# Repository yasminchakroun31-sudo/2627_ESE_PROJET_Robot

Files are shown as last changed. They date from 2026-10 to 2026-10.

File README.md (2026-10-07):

# 2627_ESE_PROJET_PAC-Man🤖🗑️
PAC-Man 

### Équipe
- **Yesmine Chakroun** (yasminechakroun31-sudo)
- **Wejdene Hazami**
- **Roua Jaouadi**

### Objectif
Concevoir un robot mobile qui repère, attrape, différencie et dépose des canettes en fonction de leur couleur.

### Timeline
- **Challenge:** 15 janvier 2027
- **Fin semestre:** 16 janvier 2027

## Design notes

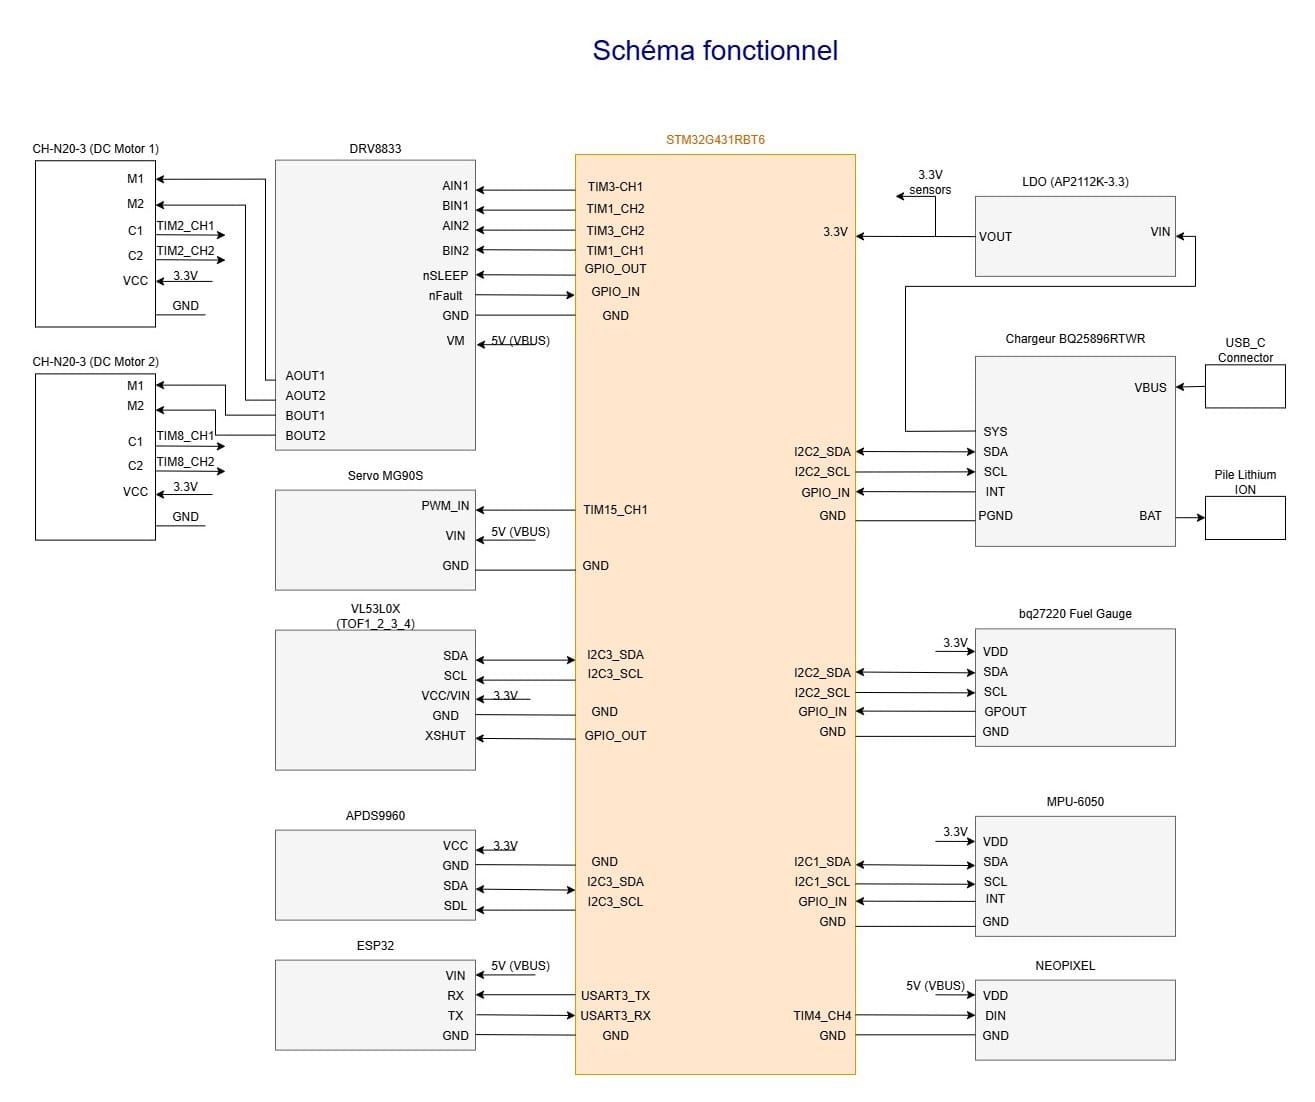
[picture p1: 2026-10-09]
docs/schema_fonctionnel.png/Schéma_Fonctionnel.jpeg

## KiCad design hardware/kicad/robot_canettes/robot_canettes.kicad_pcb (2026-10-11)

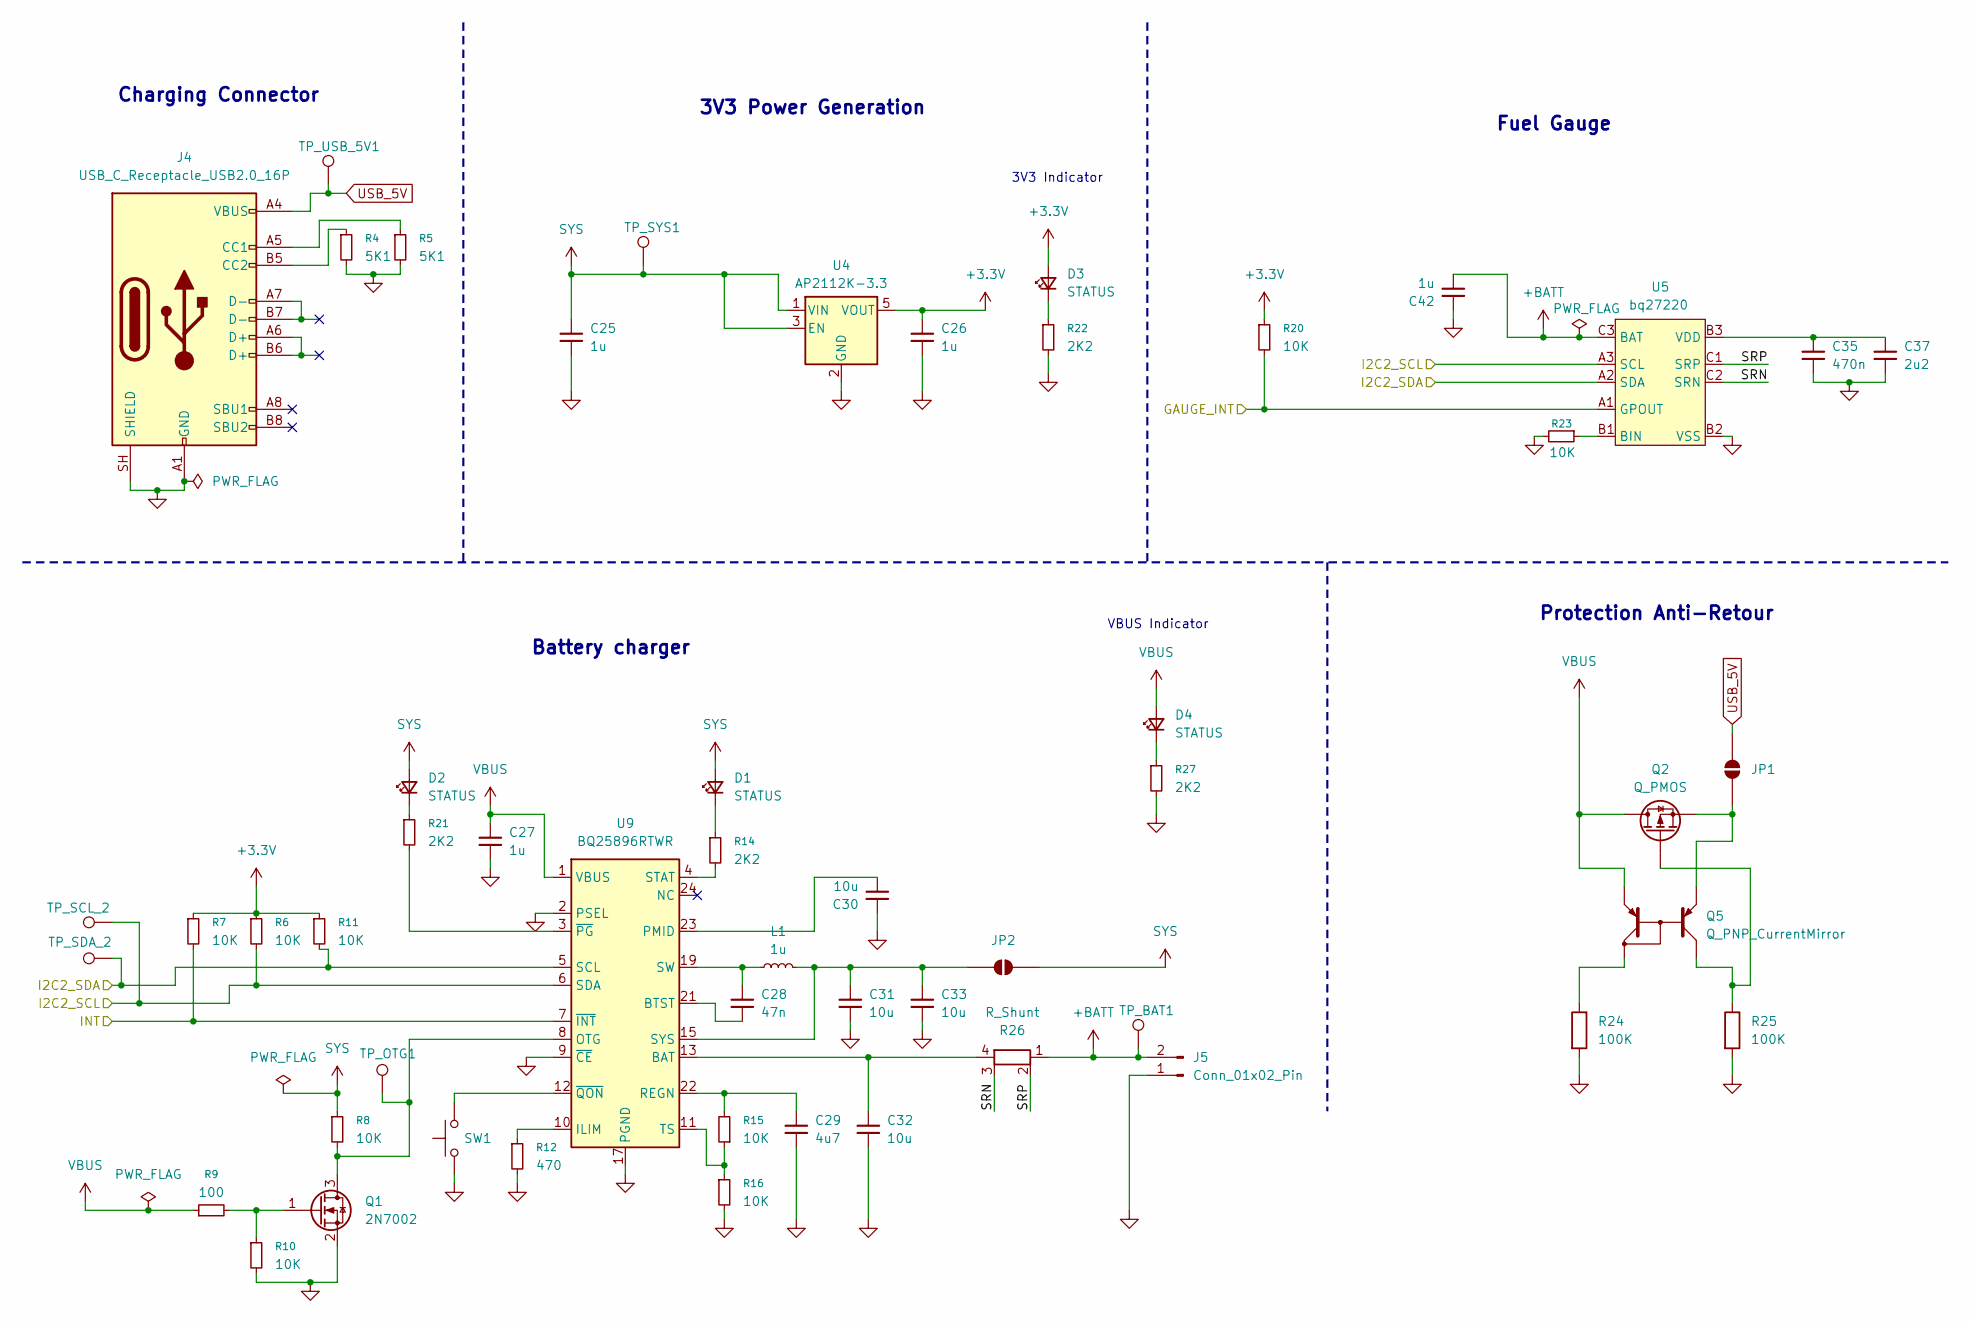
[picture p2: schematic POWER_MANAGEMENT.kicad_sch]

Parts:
C25, C26, C27, C42: 1u; C_0402_1005Metric; JLCPCB Part # C52923
C28: 47n; C_0402_1005Metric; JLCPCB Part # C5254486
C29: 4u7; C_0402_1005Metric; JLCPCB Part # C368809
C30, C31, C32, C33: 10u; C_0603_1608Metric; JLCPCB Part # C19702
C35: 470n; C_0402_1005Metric; JLCPCB Part # C2443202
C37: 2u2; C_0402_1005Metric; JLCPCB Part # C107370
D1: STATUS; LED_0603_1608Metric; JLCPCB Part # C2287
D2, D3, D4: STATUS; LED_0603_1608Metric; JLCPCB Part # C72043
J4: USB_C_Receptacle_USB2.0_16P; USB_C_Receptacle_GCT_USB4105-xx-A_16P_TopMnt_Horizontal; JLCPCB Part # C2765186
J5: Conn_01x02_Pin; JST_PH_B2B-PH-K_1x02_P2.00mm_Vertical
JP1, JP2: SolderJumper-2_P1.3mm_Open_Pad1.0x1.5mm
L1: 1u; L_APV_ANR4010; JLCPCB Part # C354578
Q1: 2N7002; SOT-23; JLCPCB Part # C8485
Q2: Q_PMOS; SOT-23; JLCPCB Part # C177033
Q5: Q_PNP_CurrentMirror; SOT-363_SC-70-6; JLCPCB Part # C42387345
R4, R5: 5K1; R_0402_1005Metric; JLCPCB Part # C25905
R6, R7, R8, R10, R11, R15, R16, R20, R23: 10K; R_0402_1005Metric; JLCPCB Part # C844714
R9: 100; R_0402_1005Metric; JLCPCB Part # C25076
R12: 470; R_0402_1005Metric; JLCPCB Part # C25117
R14, R21, R22, R27: 2K2; R_0402_1005Metric; JLCPCB Part # C25879
R24, R25: 100K; R_0603_1608Metric; JLCPCB Part # C25803
R26: R_Shunt; R_Shunt_Ohmite_LVK12; JLCPCB Part # C500740
SW1: SW_SPST_Omron_B3FS-101xP; JLCPCB Part # C271753
TP_BAT1: TestPoint_Pad_D1.5mm
TP_OTG1: TestPoint_Pad_D1.5mm
TP_SCL_2: TestPoint_Pad_D1.5mm
TP_SDA_2: TestPoint_Pad_D1.5mm
TP_SYS1: TestPoint_Pad_D1.5mm
TP_USB_5V1: TestPoint_Pad_D1.5mm
U4: AP2112K-3.3; SOT-23-5; JLCPCB Part # C51118
U5: bq27220; BGA-9_3x3_1.62x1.58mm_Pitch0.5mm; JLCPCB Part # C528617
U9: BQ25896RTWR; Texas_RTW_WQFN-24-1EP_4x4mm_P0.5mm_EP2.7x2.7mm_ThermalVias; JLCPCB Part # C181475

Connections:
+3.3V: C26.1, D3.2 (A), R6.1, R7.1, R11.1, R20.1, U4.5 (VOUT); also elsewhere on the board
+BATT: C42.2, J5.2, R26.1, TP_BAT1.1 (1_1), U5.C3 (BAT)
/MCU/GAUGE_INT: R20.2, U5.A1 (GPOUT); also elsewhere on the board
/MCU/I2C2_SCL: R6.2, TP_SCL_2.1 (1_1), U5.A3 (SCL), U9.6 (SDA); also elsewhere on the board
/MCU/I2C2_SDA: R11.2, TP_SDA_2.1 (1_1), U5.A2 (SDA), U9.5 (SCL); also elsewhere on the board
/MCU/INT: R7.2, U9.7 (~INT); also elsewhere on the board
/POWER_MANAGEMENT/SRN: R26.3, U5.C2 (SRN)
/POWER_MANAGEMENT/SRP: R26.2, U5.C1 (SRP)
unnamed: C28.1, L1.1, U9.19 (SW), U9.20 (SW)
unnamed: C32.1, R26.4, U9.13 (BAT), U9.14 (BAT)
unnamed: D1.1 (K), R14.1
unnamed: D2.1 (K), R21.1
unnamed: D3.1 (K), R22.1
unnamed: D4.1 (K), R27.1
unnamed: J4.A5 (CC1), R5.1
unnamed: J4.B5 (CC2), R4.1
unnamed: JP1.1 (A), Q2.2 (S), Q5.1 (E1)
unnamed: C31.1, C33.1, JP2.2 (B), L1.2, U9.15 (SYS), U9.16 (SYS)
unnamed: Q1.3 (D), R8.2, TP_OTG1.1 (1_1), U9.8 (OTG)
unnamed: Q1.1 (G), R9.2, R10.1
unnamed: Q2.1 (G), Q5.6 (C1), R25.1
unnamed: Q5.3 (C2), R24.1
unnamed: R23.1, U5.B1 (BIN)
unnamed: C35.1, C37.1, U5.B3 (VDD)
unnamed: C28.2, U9.21 (BTST)
unnamed: R12.1, U9.10 (ILIM)
unnamed: C30.2, U9.23 (PMID)
unnamed: C29.1, R15.2, U9.22 (REGN)
unnamed: R14.2, U9.4 (STAT)
unnamed: R15.1, R16.1, U9.11 (TS)
unnamed: R21.2, U9.3 (~PG)
unnamed: SW1.2, U9.12 (~QON)
SYS: C25.1, D1.2 (A), D2.2 (A), JP2.1 (A), R8.1, TP_SYS1.1 (1_1), U4.1 (VIN), U4.3 (EN)
USB_5V: J4.A4 (VBUS), J4.A9 (VBUS), J4.B4 (VBUS), J4.B9 (VBUS), JP1.2 (B), TP_USB_5V1.1 (1_1)
VBUS: C27.1, D4.2 (A), Q2.3 (D), Q5.4 (E2), R9.1, U9.1 (VBUS); also elsewhere on the board

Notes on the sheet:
Battery charger
Charging Connector
3V3 Indicator
Fuel Gauge
3V3 Power Generation
Protection Anti-Retour
VBUS Indicator

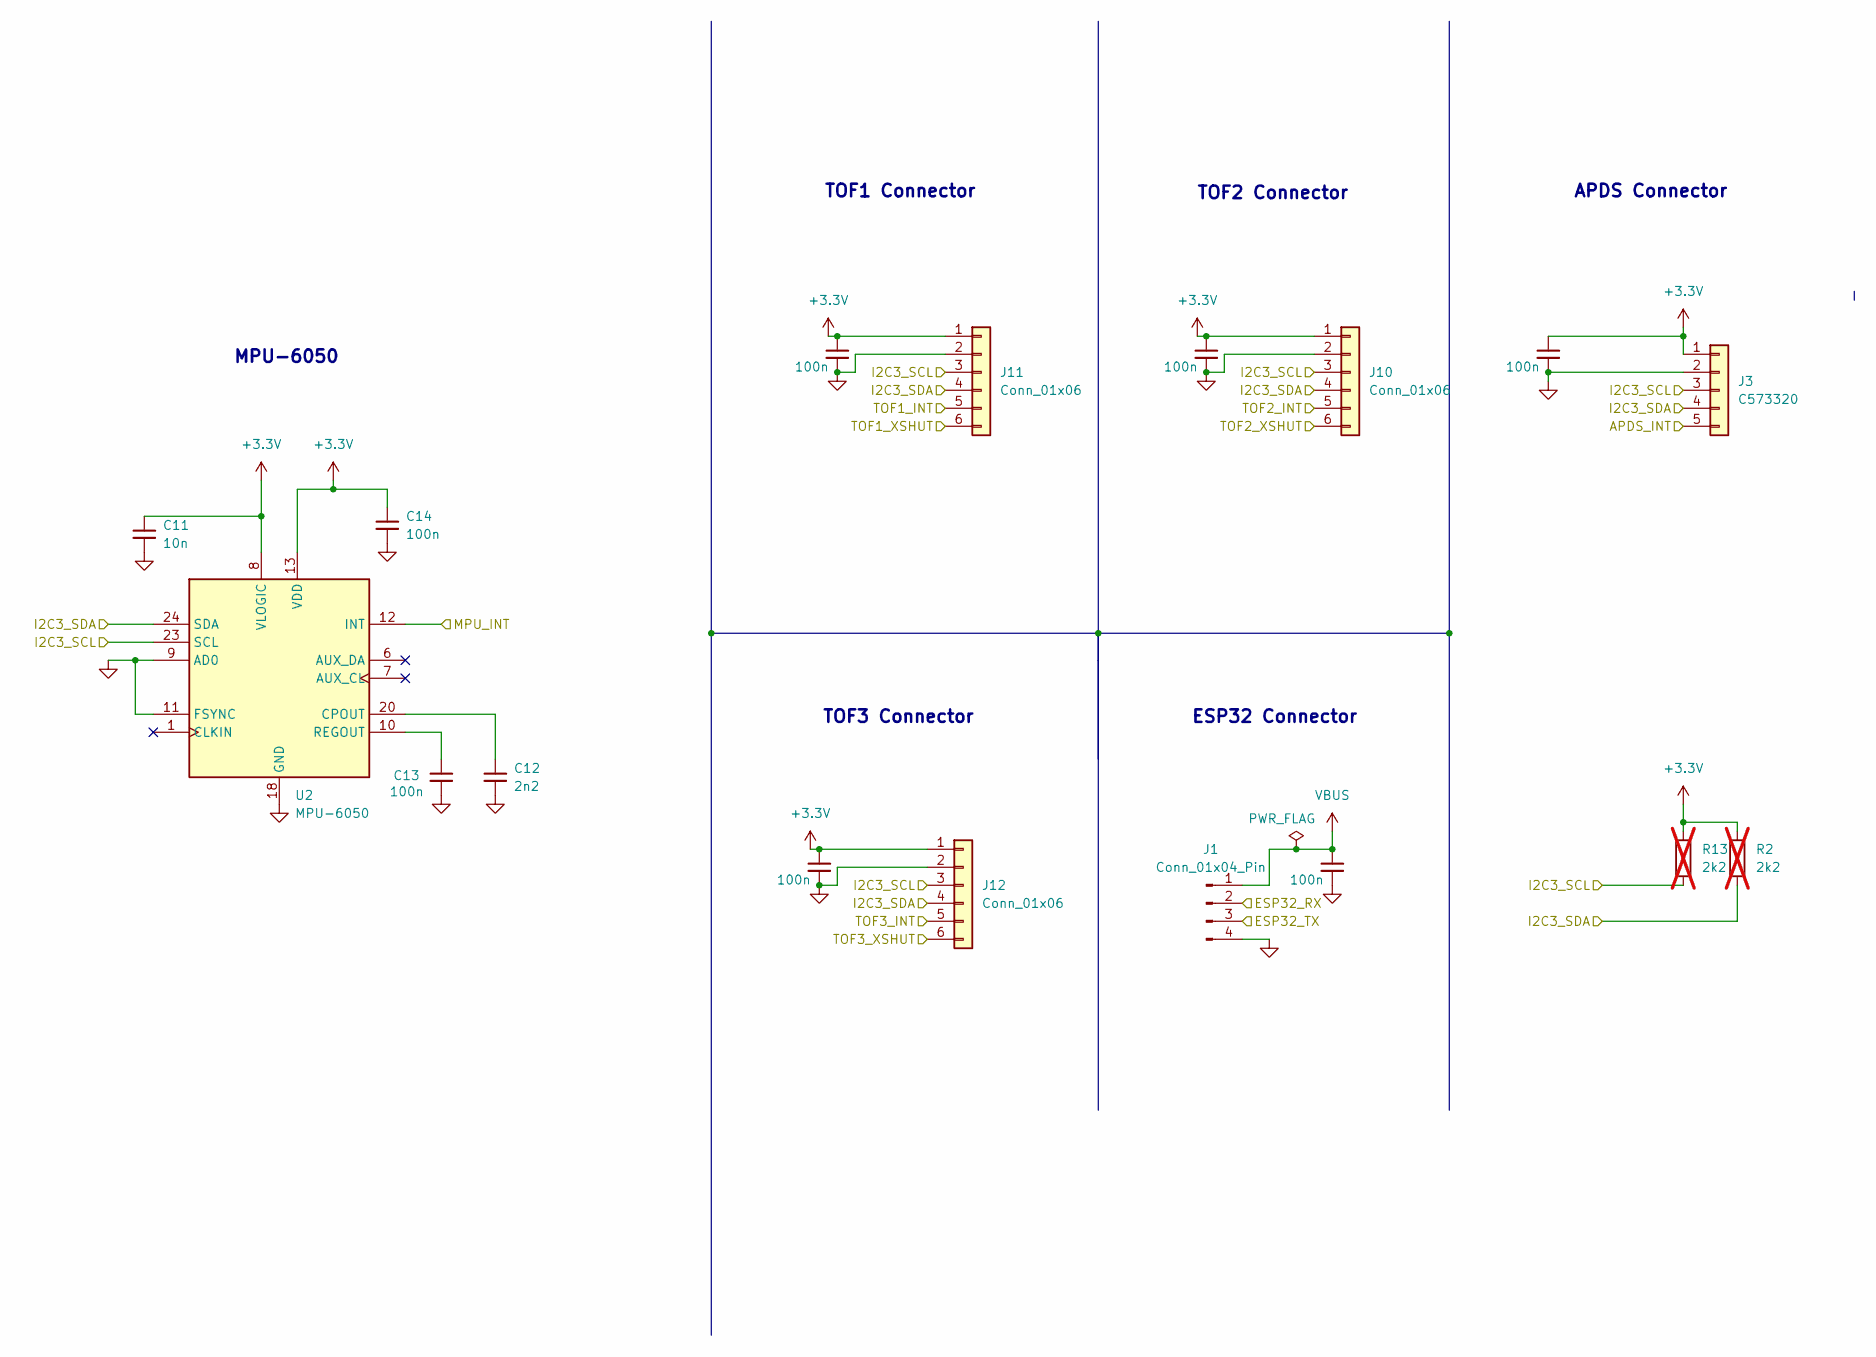
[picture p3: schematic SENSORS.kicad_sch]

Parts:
C11: 10n; C_0402_1005Metric; JLCPCB PART # C15195
C12: 2n2; C_0402_1005Metric; JLCPCB PART # C1531
C13, C14, C38, C39, C40, C41, C43: 100n; C_0402_1005Metric; JLCPCB PART # C1525
J1: Conn_01x04_Pin; JST_PH_B4B-PH-K_1x04_P2.00mm_Vertical
J3: C573320; JST_PH_B5B-PH-K_1x05_P2.00mm_Vertical; JLCPCB PART# C573320
J10, J11, J12: Conn_01x06; JST_PH_B6B-PH-K_1x06_P2.00mm_Vertical
R2, R13: 2k2; R_0402_1005Metric; JLCPCB PART # C174143; not fitted
U2: MPU-6050; InvenSense_QFN-24_4x4mm_P0.5mm; JLCPCB PART # C24112

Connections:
+3.3V: C11.1, C14.1, C38.1, C39.1, C40.1, C41.1, J3.1, J10.1, J11.1, J12.1, R2.1, R13.1, U2.8 (VLOGIC), U2.13 (VDD); also elsewhere on the board
/MCU/APDS_INT: J3.5; also elsewhere on the board
/MCU/ESP32_RX: J1.3; also elsewhere on the board
/MCU/ESP32_TX: J1.2; also elsewhere on the board
/MCU/I2C3_SCL: J3.3, J10.3, J11.3, J12.3, R13.2, U2.23 (SCL); also elsewhere on the board
/MCU/I2C3_SDA: J3.4, J10.4, J11.4, J12.4, R2.2, U2.24 (SDA); also elsewhere on the board
/MCU/MPU_INT: U2.12 (INT); also elsewhere on the board
/MCU/TOF1_INT: J12.5; also elsewhere on the board
/MCU/TOF1_XSHUT: J12.6; also elsewhere on the board
/MCU/TOF2_INT: J10.5; also elsewhere on the board
/MCU/TOF2_XSHUT: J10.6; also elsewhere on the board
/MCU/TOF3_INT: J11.5; also elsewhere on the board
/MCU/TOF3_XSHUT: J11.6; also elsewhere on the board
unnamed: C12.1, U2.20 (CPOUT)
unnamed: C13.1, U2.10 (REGOUT)
VBUS: C43.1, J1.1; also elsewhere on the board

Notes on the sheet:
TOF1 Connector
APDS Connector
ESP32 Connector
TOF2 Connector
MPU-6050
TOF3 Connector

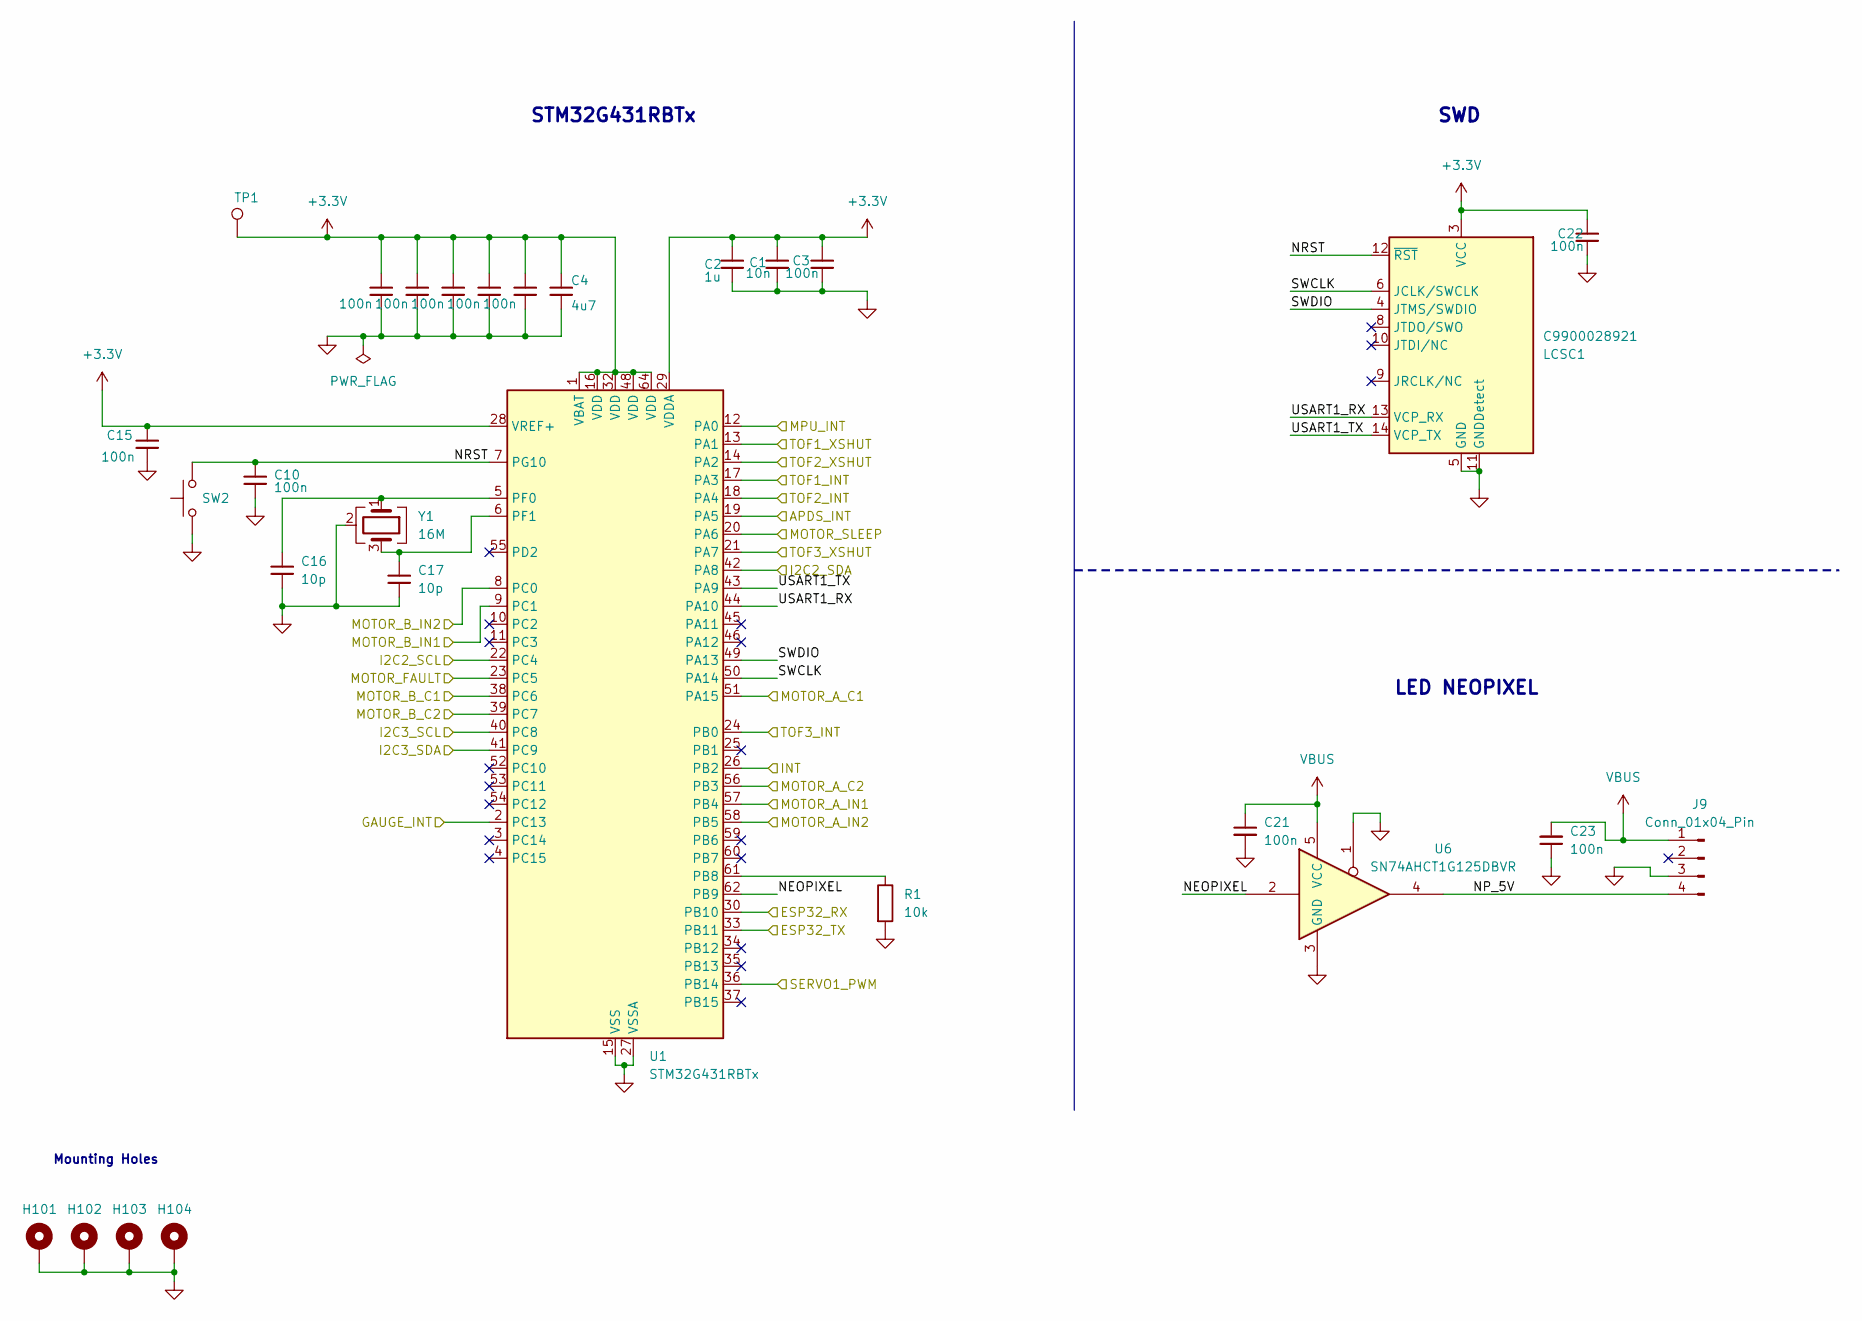
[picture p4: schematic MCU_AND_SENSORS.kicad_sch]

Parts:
C1: 10n; C_0402_1005Metric; JLCPCB PART# C15195
C2: 1u; C_0603_1608Metric; JLCPCB PART # C141772
C3, C6, C7, C8, C9, C10, C15, C22: 100n; C_0402_1005Metric; JLCPCB PART # C1525
C4: 4u7; C_0603_1608Metric
C5: 100n; C_0402_1005Metric
C16, C17: 10p; C_0603_1608Metric; JLCPCB PART # C123155
C21, C23: 100n; C_0402_1005Metric; JLCPCB Part # C1525
H101, H102, H103, H104: MountingHole_Pad; MountingHole_3.2mm_M3_Pad_Via
J9: Conn_01x04_Pin; JST_PH_B4B-PH-K_1x04_P2.00mm_Vertical; JLCPCB Part # C2691448
LCSC1: C9900028921; PinHeader_2x07_P1.27mm_Vertical_SMD; JLCPCB PART # C9900028921
R1: 10k; R_0402_1005Metric; JLCPCB PART # C174175
SW2: SW_SPST_Omron_B3FS-101xP; JLCPCB Part # C271753
TP1: TestPoint; TestPoint_Pad_D1.5mm
U1: STM32G431RBTx; LQFP-64_10x10mm_P0.5mm; JLCPCB PART # C431633
U6: SN74AHCT1G125DBVR; SOT-23-5; JLCPCB Part # C20617903
Y1: 16M; Crystal_SMD_EuroQuartz_MT-4Pin_3.2x2.5mm; JLCPCB PART # C13738

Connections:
+3.3V: C1.1, C2.1, C3.1, C4.1, C5.1, C6.1, C7.1, C8.1, C9.1, C15.1, C22.1, LCSC1.3 (VCC), TP1.1 (1_1), U1.1 (VBAT), U1.16 (VDD), U1.28 (VREF+), U1.29 (VDDA), U1.32 (VDD), U1.48 (VDD), U1.64 (VDD); also elsewhere on the board
/MCU/APDS_INT: U1.19 (PA5); also elsewhere on the board
/MCU/ESP32_RX: U1.30 (PB10); also elsewhere on the board
/MCU/ESP32_TX: U1.33 (PB11); also elsewhere on the board
/MCU/GAUGE_INT: U1.2 (PC13); also elsewhere on the board
/MCU/I2C2_SCL: U1.22 (PC4); also elsewhere on the board
/MCU/I2C2_SDA: U1.42 (PA8); also elsewhere on the board
/MCU/I2C3_SCL: U1.40 (PC8); also elsewhere on the board
/MCU/I2C3_SDA: U1.41 (PC9); also elsewhere on the board
/MCU/INT: U1.26 (PB2); also elsewhere on the board
/MCU/MOTOR_A_C1: U1.51 (PA15); also elsewhere on the board
/MCU/MOTOR_A_C2: U1.56 (PB3); also elsewhere on the board
/MCU/MOTOR_A_IN1: U1.57 (PB4); also elsewhere on the board
/MCU/MOTOR_A_IN2: U1.58 (PB5); also elsewhere on the board
/MCU/MOTOR_B_C1: U1.38 (PC6); also elsewhere on the board
/MCU/MOTOR_B_C2: U1.39 (PC7); also elsewhere on the board
/MCU/MOTOR_B_IN1: U1.9 (PC1); also elsewhere on the board
/MCU/MOTOR_B_IN2: U1.8 (PC0); also elsewhere on the board
/MCU/MOTOR_FAULT: U1.23 (PC5); also elsewhere on the board
/MCU/MOTOR_SLEEP: U1.20 (PA6); also elsewhere on the board
/MCU/MPU_INT: U1.12 (PA0); also elsewhere on the board
/MCU/NEOPIXEL: U1.62 (PB9), U6.2
/MCU/NP_5V: J9.4, U6.4
/MCU/NRST: C10.1, LCSC1.12 (~RST), SW2.2, U1.7 (PG10)
/MCU/SERVO1_PWM: U1.36 (PB14); also elsewhere on the board
/MCU/SWCLK: LCSC1.6 (JCLK/SWCLK), U1.50 (PA14)
/MCU/SWDIO: LCSC1.4 (JTMS/SWDIO), U1.49 (PA13)
/MCU/TOF1_INT: U1.17 (PA3); also elsewhere on the board
/MCU/TOF1_XSHUT: U1.13 (PA1); also elsewhere on the board
/MCU/TOF2_INT: U1.18 (PA4); also elsewhere on the board
/MCU/TOF2_XSHUT: U1.14 (PA2); also elsewhere on the board
/MCU/TOF3_INT: U1.24 (PB0); also elsewhere on the board
/MCU/TOF3_XSHUT: U1.21 (PA7); also elsewhere on the board
/MCU/USART1_RX: LCSC1.13 (VCP_RX), U1.44 (PA10)
/MCU/USART1_TX: LCSC1.14 (VCP_TX), U1.43 (PA9)
unnamed: R1.1, U1.61 (PB8)
unnamed: C16.1, U1.5 (PF0), Y1.1
unnamed: C17.1, U1.6 (PF1), Y1.3
VBUS: C21.1, C23.2, J9.1, U6.5 (VCC); also elsewhere on the board

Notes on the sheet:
LED NEOPIXEL
SWD
Mounting Holes
STM32G431RBTx

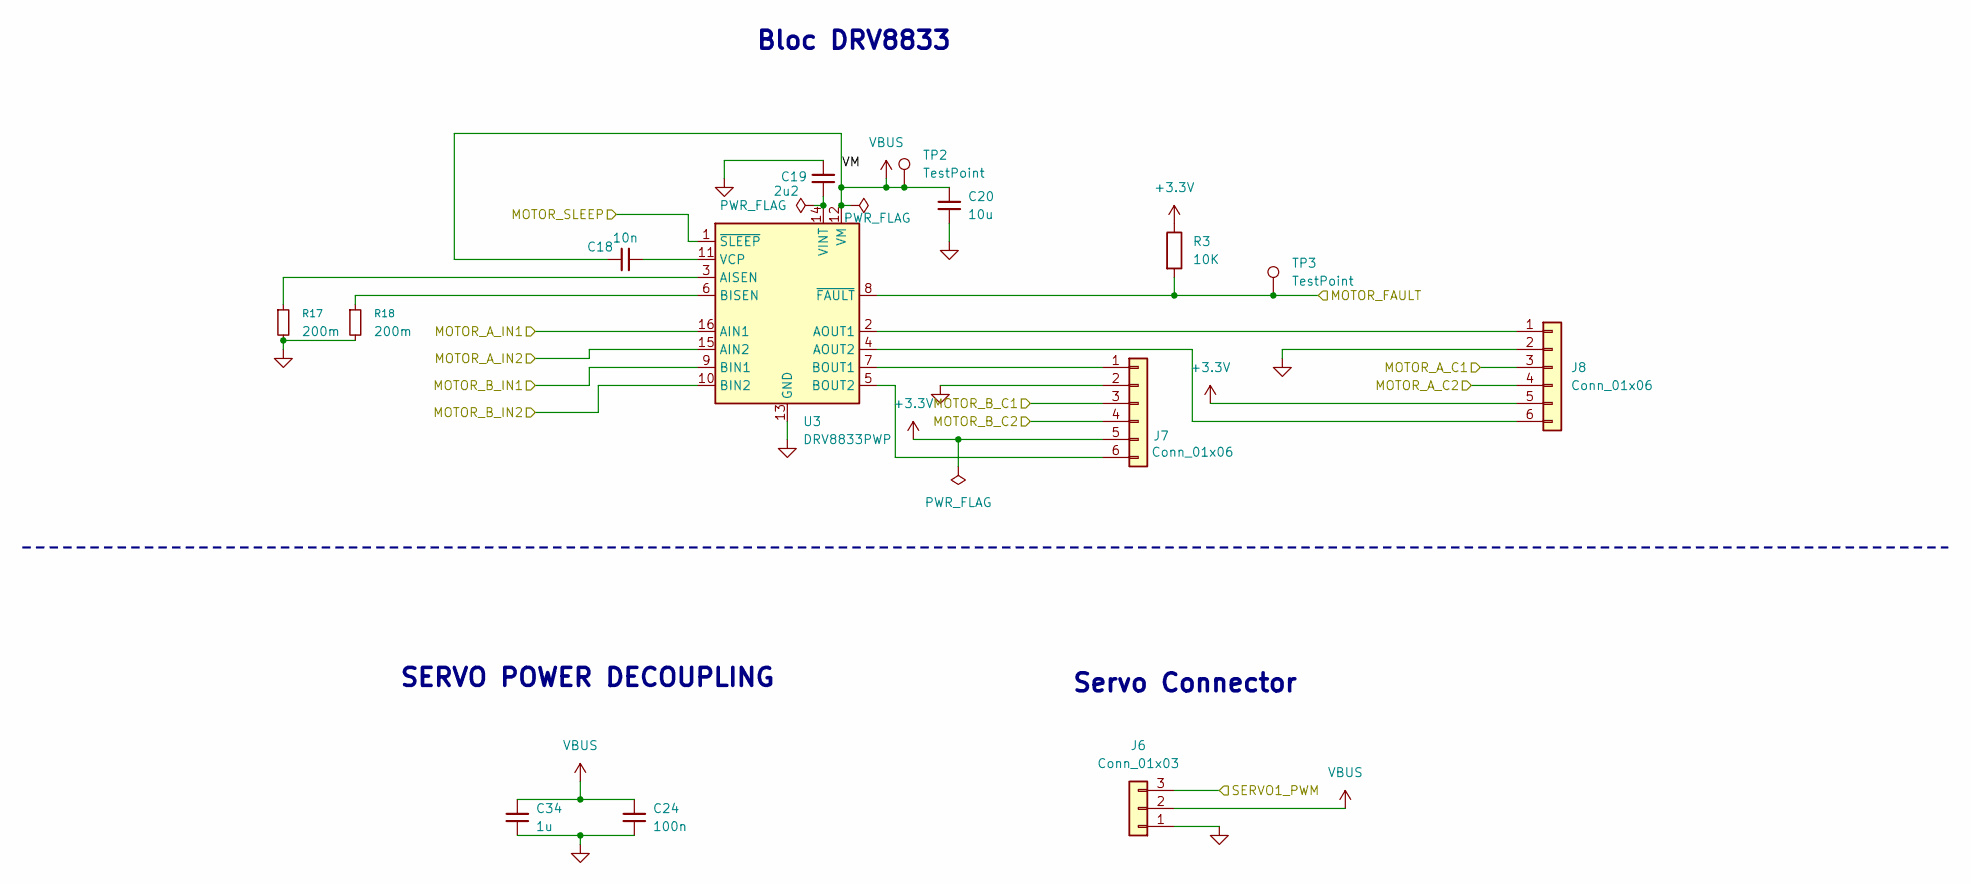
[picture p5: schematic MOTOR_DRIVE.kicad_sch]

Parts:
C18: 10n; C_0402_1005Metric; JLCPCB Part # C15195
C19: 2u2; C_0402_1005Metric; JLCPCB Part # C12530
C20: 10u; C_0805_2012Metric; JLCPCB Part # C380332
C24: 100n; C_0402_1005Metric; JLCPCB Part # C1525
C34: 1u; C_0402_1005Metric
J6: Conn_01x03; JST_PH_B3B-PH-K_1x03_P2.00mm_Vertical; JLCPCB Part # C49257
J7, J8: Conn_01x06; JST_PH_B6B-PH-K_1x06_P2.00mm_Vertical; JLCPCB Part # C265069
R3: 10K; R_0402_1005Metric; JLCPCB Part # C844714
R17, R18: 200m; R_1206_3216Metric; JLCPCB PART # C1727756
TP2, TP3: TestPoint; TestPoint_Pad_D1.5mm
U3: DRV8833PWP; HTSSOP-16-1EP_4.4x5mm_P0.65mm_EP3.4x5mm_Mask2.46x2.31mm; JLCPCB Part # C50506

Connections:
+3.3V: J7.5, J8.5, R3.1; also elsewhere on the board
/MCU/MOTOR_A_C1: J8.3; also elsewhere on the board
/MCU/MOTOR_A_C2: J8.4; also elsewhere on the board
/MCU/MOTOR_A_IN1: U3.16 (AIN1); also elsewhere on the board
/MCU/MOTOR_A_IN2: U3.15 (AIN2); also elsewhere on the board
/MCU/MOTOR_B_C1: J7.3; also elsewhere on the board
/MCU/MOTOR_B_C2: J7.4; also elsewhere on the board
/MCU/MOTOR_B_IN1: U3.9 (BIN1); also elsewhere on the board
/MCU/MOTOR_B_IN2: U3.10 (BIN2); also elsewhere on the board
/MCU/MOTOR_FAULT: R3.2, TP3.1 (1_1), U3.8 (~FAULT); also elsewhere on the board
/MCU/MOTOR_SLEEP: U3.1 (~SLEEP); also elsewhere on the board
/MCU/SERVO1_PWM: J6.3; also elsewhere on the board
unnamed: J7.1, U3.7 (BOUT1)
unnamed: J7.6, U3.5 (BOUT2)
unnamed: J8.1, U3.2 (AOUT1)
unnamed: J8.6, U3.4 (AOUT2)
unnamed: R17.1, U3.3 (AISEN)
unnamed: R18.1, U3.6 (BISEN)
unnamed: C18.2, U3.11 (VCP)
unnamed: C19.2, U3.14 (VINT)
VBUS: C18.1, C20.1, C24.1, C34.1, J6.2, TP2.1 (1_1), U3.12 (VM); also elsewhere on the board

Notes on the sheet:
Servo Connector
SERVO POWER DECOUPLING
Bloc DRV8833

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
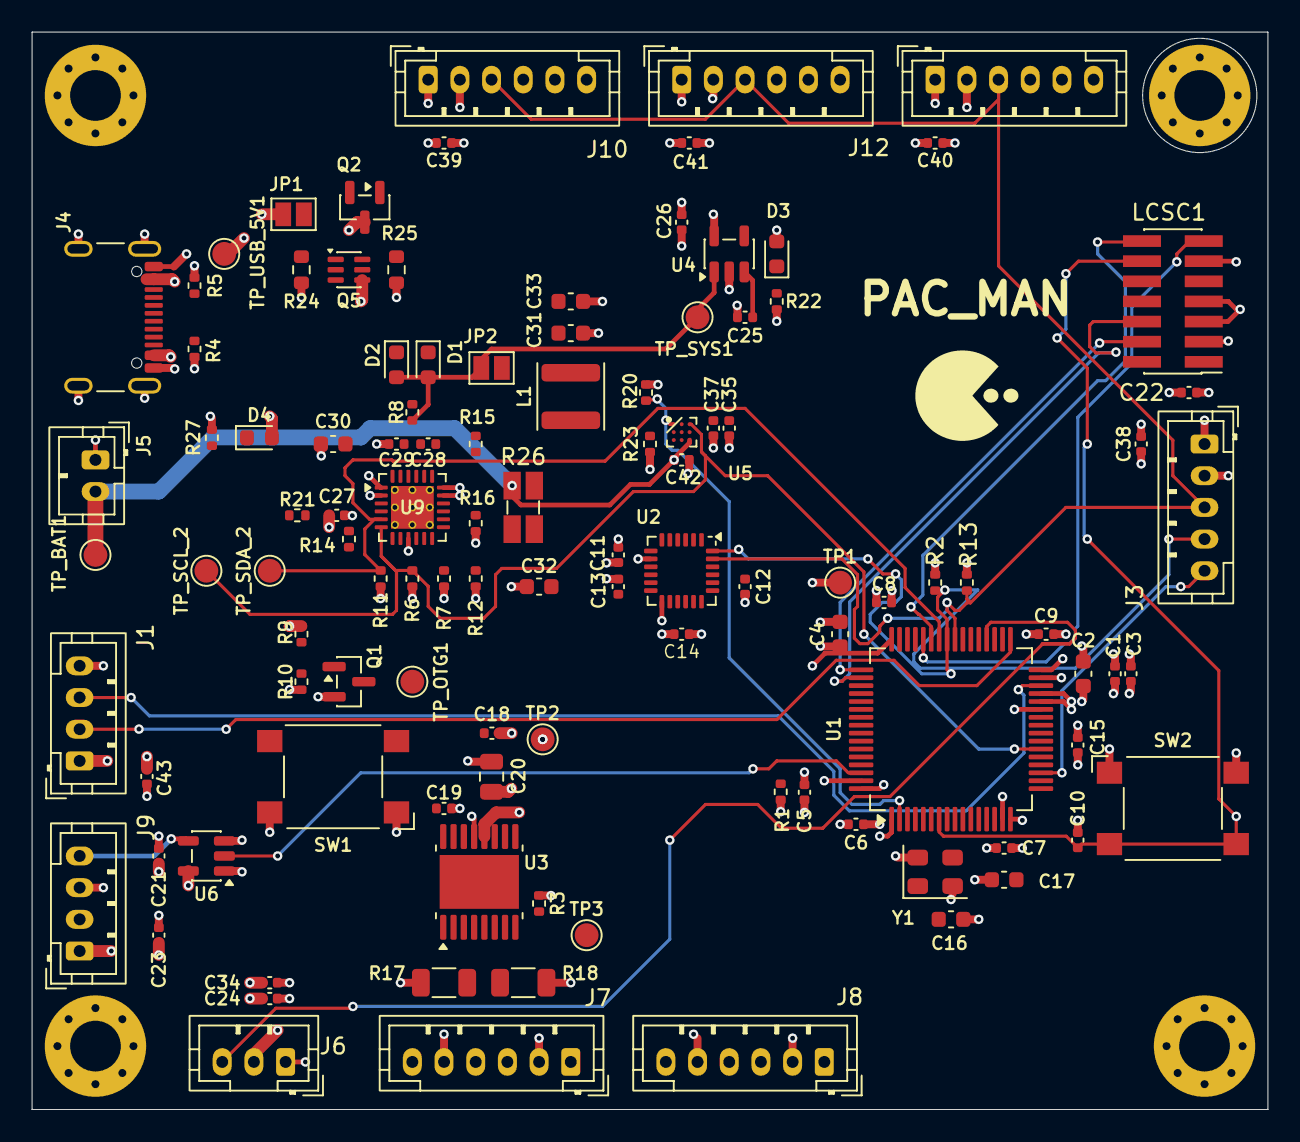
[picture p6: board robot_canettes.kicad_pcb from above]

Board: 4 copper layers, 78.0 x 68.0 mm, 113 parts (0 on the bottom side), 79 nets.

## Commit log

2026-10-07 Initialisation du projet robot et ajout du PCB
    [MCU_AND_SENSORS.kicad_sch, MOTOR_DRIVE.kicad_sch, POWER_MANAGEMENT.kicad_sch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]
2026-10-07 Mise a jour du projet, correction du nom de la feuille sensors
    [SENSORS.kicad_sch, robot_canettes.kicad_pcb]
2026-10-07 Description de vos modifications
    [robot_canettes.kicad_pcb]
2026-10-07 Mise à jour de l'emplacement des composants
    [MCU_AND_SENSORS.kicad_sch, MOTOR_DRIVE.kicad_sch, POWER_MANAGEMENT.kicad_sch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]
2026-10-08 Modification du projet
    [robot_canettes.kicad_pcb]
2026-10-08 Mise à jour PCB depuis le zip
    [MCU_AND_SENSORS.kicad_sch, robot_canettes.kicad_pcb]
2026-10-08 Update PCB routing and placement
    [robot_canettes.kicad_pcb]
2026-10-11 Update robot PCB
    [robot_canettes.kicad_pcb]
2026-10-12 Mise à jour du PCB
2026-10-12 Mise à jour du PCB (routage)
2026-10-16 Final PCB LAYOUT
2026-10-19 Mise a jour des schemas, layout final, routage et génération des fichiers de fabrication de la carte
